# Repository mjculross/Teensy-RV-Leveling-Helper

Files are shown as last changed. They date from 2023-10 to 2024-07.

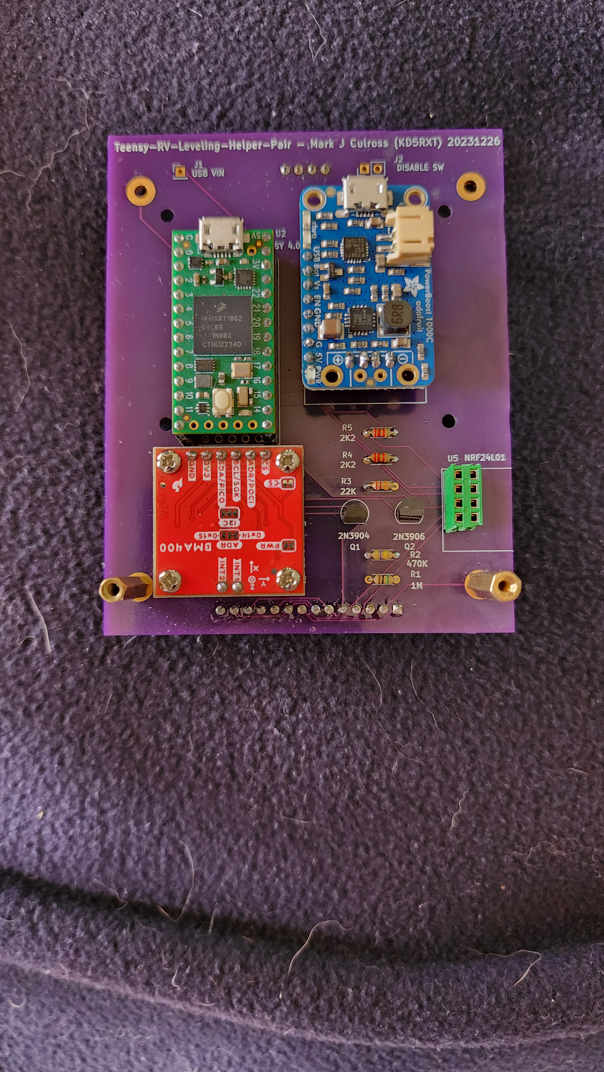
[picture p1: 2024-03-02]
photos/TRLH - pcb component side.jpg

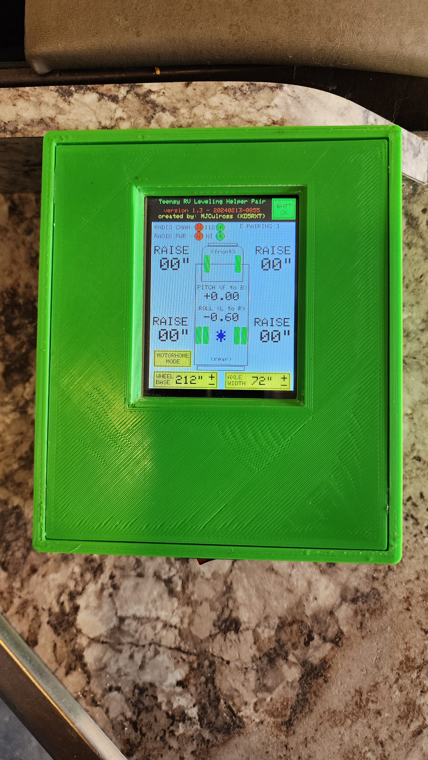
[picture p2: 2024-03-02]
photos/TRLH - display after leveling.jpg

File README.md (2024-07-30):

# Teensy-RV-Leveling-Helper
Teensy RV Leveling Helper using Teensy 4.0 + BMA400 Triple Axis Accelerometer Breakout + ILI9341 Color 320x240 TFT Touchscreen display + NRF24L01 radio

TRLH - RV mode main screen

This project came about after we acquired a used RV motorhome & I quickly grew tired of the following process of attempting to level the RV:
   1) park the RV on a particular site
   2) look at the bubble level on the kitchen counter to determine "level or not"
   3) make/revise my best guess as to how many blocks are required on each wheel to attain "level"
   4) drive the RV up on the best guess number of blocks
   5) if the RV is "level", then you're DONE !!
   6) if the RV is not yet "level", then drive the RV down off of the best guess number of blocks
   7) goto 3) above & repeat several times (until either we're close enough, or I get fed up, whichever comes first)

Using the TRLH makes this process much more convenient & quick as follows:
   1) park your RV where you want it to ultimately rest for the duration of your stay
   2) apply power to the inside TRLH & place it on the kitchen counter inside the RV
      (which provides a non-moving reference plane for the entire RV)
   3) if you are using a second TRLH as a remote display, apply power to the remote TRLH
      (the two units will establish sync over the radio & the remote unit will ignore its
      own accelerometer data, and will instead perform all leveling calculations using
      the accelerometer data received from the inside TRLH over the NRF24L01 radio -
      NOTE: if you're not using the remote TRLH, the inside TRLH will still operate as a
      single unit)
   4) take note of the leveling solution displayed (indicating results of calculating
      how many inches to raise any of the wheels in order to bring the RV to a perfectly
      level position)
   5) back the RV away sufficiently to leave room to put the ramps into place
   6) build and place the required ramps (using 1" blocks) to raise the wheels as indicated
   7) drive the RV up onto the newly built leveling ramps
   8) verify that the TRLH now shows 0" for each wheel - LEVELING SUCCESS !! (Note that
      anything within 1" of level is sufficient for the comfort of the occupants, as
      well as for the equipment, primarily the refrigerator)
   9) sit back & enjoy a cold drink of your choice

This project incorporates the following:

   HARDWARE:

      Teensy 4.0
         available from PJRC.com https://www.pjrc.com/teensy-4-0/

      ILI9341 Color 320x240 TFT Touchscreen display
         available from PJRC.com https://www.pjrc.com/store/display_ili9341_touch.html

      HiLetgo NRF24L01+ Wireless Transceiver Module 2.4GHz
         available from https://www.amazon.com/gp/product/B00LX47OCY
  
      BMA400 Triple Axis Accelerometer Breakout
         available from Sparkfun https://www.sparkfun.com/products/21208

      PowerBoost 1000 Charger - Rechargeable 5V Lipo USB Boost @ 1A - 1000C
         available from Adafruit https://www.adafruit.com/product/2465
         
      Lithium Ion Polymer Battery - 3.7v 2500mAh
         available from Adafruit https://www.adafruit.com/product/328

   This project uses touchscreen input & color display to create a visual (graphical) indication of how many inches of leveling blocks are required to be put under each wheel of an RV to level it
  
   This project uses the ILI9341_t3 library, which has been optimized for use with the Teensy TFT display, as well as the XPT2046_Touchscreen.h touchscreen library for that same display

   This project (optionally) uses the NRF24L01 wireless transceiver module to allow two TRLH units to communicate, using one as the inside unit taking measurements, and the other as a remote display
   
   This project specifically uses the SparkFun BMA400 support library (SparkFun_BMA400_Arduino_Library.h) which can be added using the Arduino IDE library manager.

   This project allows & stores configurable wheel base (front to back wheels distance) from 60" to 255".

   This project allows & stores configurable wheel distance (front wheels, left to right distance) from 60" to 84".

   Internet reference (with equation derivation) for transforming accelerometer x,y,z vector data into pitch & roll angles:

      https://mwrona.com/posts/accel-roll-pitch/

   The specific DPDT switch that I use for power control (& for which the 3D printed case is designed) is the Carling Technologies 62115929-0-0-V, available from digikey as part number 432-1252-ND (https://www.digikey.com/en/products/detail/carling-technologies/62115929-0-0-V/3025077).

   An Adafruit microUSB panel mount extension cable Product ID 3258 (https://www.adafruit.com/product/3258) is mounted on the side wall of the case.  The cable is split such that the USB 5VDC line connects to the USB input pin on the Adafruit PowerBoost 1000C to provide power & battery charging, while the remaining GROUND, D-, & D+ signals connect to the microUSB connector on the Teensy to allow (re)programming without opening the case.

   This project implements the following:

      1) read the XYZ vector from the BMA400 triple axis accelerometer breakout
      2) use the XYZ vector to calculate PITCH and ROLL values for the current plane of the RV/trailer orientation
      3) use the calculated PITCH and ROLL values to determine the highest wheel/point (which will not require any blocks)
      4) use the calculated PITCH and ROLL values to determine the number of inches of blocks required for the remaining wheels/points to achieve "level"
      5) update the display with the current results once per second (& average all values otherwise)
      6) repeat

UPDATE NOTES for version 1.6 dated 07/20/2024 @0635:

   Updated TRAILER MODE such that is now indicates LOWER or RAISE values up to 24" for the
   hitch, and RAISE values up to 12" for the wheels.
   
UPDATE NOTES for version 1.4 dated 04/05/2024 @1335:

   Now, two units can be used & they talk to each other using NRF24L01 wireless modules.
   The first unit powered on will assume that it is the "INSIDE" unit (which is actually
   reading its onboard BMA400 accelerometer & displaying the leveling recommendations from
   the calculated pitch & roll).  The second unit will assume that it is the "OUTSIDE" unit
   (which is ignoring its onboard BMA400, and is instead displaying the leveling
   recommendations calculated using the pitch & roll data received over the NRF24L01
   wireless link from the "INSIDE" unit).  This way, leveling can be achieved without the
   need for running back & forth between inside (to look at the Teensy-RV-Leveling-Helper)
   & outside (to make adjustments).  Any unit can also be used by itself...it does not have
   to have a partner to work.  The latest firmware also automatically detects the lack of
   the NRF24L01 module & operates successfully without the radio as a standalone unit.

   EASTER EGG: If you hold down on the battery status display box for 5-seconds, the unit
   will change from RV LEVELING MODE to LED COLOR CONTROLLER MODE.  In this mode, with a
   WS2812B LED strip powered from the 5VDC supply & common ground with the Teensy, tie the
   data line to PIN 8 & the RV Leveling Helper can also be used to create custom LED
   patterns, with the ability to control the mode (MARQUIS, CYCLE, FADE, CROSSFADE, ZIPPER,
   & RANDOM), the brightness, the radio power level (for using another unit as a remote
   control), the radio channel (to put the LED COLOR CONTROLLER MODE on a different radio
   channel from the RV LEVELING MODE to minimize interference between them).  Up to ten
   different custom patterns can be stored in EEPROM for quick recall.  Each pattern can
   be from two to thirty-two LEDs in length.  Each LED can be set to any of over sixteen
   million colors.  You can also customize the speed for each pattern individually, as
   well as the direction of movement (FORWARD / REVERSE).  An RV Leveling Helper which
   is being operated in LED COLOR CONTROLLER MODE need not have the TFT Color Touchscreen
   installed/connected.  By shorting PIN 10 on the Teensy to ground, an RV Leveling
   Helper unit can be forced into LED COLOR CONTROLLER MODE (specifically for the case
   where you have an RV Leveling helper unit that does not have a display connected by
   which to change between the two modes, essentially making it a dedicated, stand-alone
   LED COLOR CONTROLLER).  For the RV Leveling Helper with a TFT Color Touchscreen
   installed/connected and operting in the LED COLOR CONTROLLER MODE, holding down on
   the battery display box for 5-seconds will change it back to RV LEVELING MODE.  So,
   you now have two-controllers-in-one with this new capability.
   
RV LEVELING CONTROLLER OPERATIONAL MODE:

   This project can be switched between the following primary modes of operation:
   - RV mode (four points of balance/leveling = four wheels)
   - Trailer mode (three points of balance/leveling = two wheels and the hitch)
   - Bubble mode (traditional 2-D bubble level)

MECHANICAL ASSEMBLY & CALIBRATION:

   For information on mechanical assembly and/or calibration, see the "readme" file in the "photos" folder.

ORDERING INFO:

   The compact PCB is available from OshPark here: https://oshpark.com/projects/CN9rpz97/order

CONTACT INFO:

If you have any questions, suggestions for improvement, and most especially any bug reports, please contact me at kd5rxt@arrl.net

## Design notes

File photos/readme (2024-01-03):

MECHANICAL ASSEMBLY:

For the case mechanical assembly, reference the "TeensyRVLevelingCalculator - mechanical view.pdf file to identify the unique parts by color, and perform the following:
Four M2.5 x 10mm screws (RED) are inserted from the bottom, passing thru the case bottom.  Using four M2.5 nuts (SILVER), one is installed onto each screw and hand-tightened around the case bottom.  These nuts are secured to the screw using blue threadlocker, a conservative amount of which is applied to the top of each nut such that the threadlocker liquid penetrates between the screw threads and the nuts.  Four M2.5x11+6 threaded stand-offs (MAGENTA) are secured with four M2.5 nuts (NOT SHOWN) to the prototype board (GREEN) which holds all of the electronic parts.  These stand-offs secured to the prototype board are carefully aligned with the four screws inserted thru the case bottom.  The screws are tightened only halfway into the stand-offs, leaving the ability to adjust each screw individually in order to calibrate the absolute level of the project (see the CALIBRATION section below).  Four 20mm x 5mm rubber feet (with a hole punched into the center of each) are placed on the bottom, allowing access to the adjustment screws thru the center punched holes.

CALIBRATION:

Preparation:
- set the wheel base and the axle width both to 60"

Step #1:
- place the project on a surface that is only slightly unlevel (less than 3 degrees off in any direction) with the primary slope oriented between front & back
- pay particular attention to the location placement of the project case
- note the initial PITCH angle reported (pitch_i)
- rotate the project case 180 degrees, making sure the place the project case back as close to the same spot as before
- note the rotated PITCH angle reported (pitch_r)
- rotate the project case 180 degrees, making sure the place the project case back as close to the same spot as before
- adjust the two screws at the top and/or bottom of the project case equally (raising and/or lowering the top and/or bottom of the project case as required) and repeat Step #1 as many times as necessary until pitch_i is approximately equal to the negative of pitch_r, centered around 0 degrees

Step #2:
- place the project on a surface that is only slightly unlevel (less than 3 degrees off in any direction) with the primary slope oriented between left & right
- pay particular attention to the location placement of the project case
- note the initial ROLL angle reported (roll_i)
- rotate the project case 180 degrees, making sure the place the project case back as close to the same spot as before
- note the rotated ROLL angle reported (roll_r)
- rotate the project case 180 degrees, making sure the place the project case back as close to the same spot as before
- adjust the two screws at the left and/or right side of the project case equally (raising and/or lowering the left and/or right side of the project case as required) and repeat Step #2 as many times as necessary until roll_i is approximately equal to the negative of roll_r, centered around 0 degrees

Step #3"
- repeat Step #1 above to cross-check the front-to-back calibration

Final Steps:
- reset the wheel base and the axle width as appropriate for your RV/trailer
- from the bottom of the case (thru the center punched rubber feet), apply hot glue to the tops of the adjustment screws (filling the center punched holes in the rubber feet to just shy of level with the top of the rubber feet - the tops of the rubber feet should rest on whatever surface the project is set upon, without any interference from the hot glue) in order to secure the screws in place, thus preserving the calibration just performed

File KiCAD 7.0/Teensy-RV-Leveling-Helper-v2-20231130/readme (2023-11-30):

This set of KiCAD design files is for the updated v2 (compact 3.0" x 3.8") PCB for the 20231130 version of the Teensy-RV-Leveling-Helper.

The included schematic includes external connection points as follows (with connectivity description in parentheses):
- USB VIN (input 5VDC from the external USB connector)
- DISABLE IN (use an external switch to connect the EN input on the Adafruit PowerBoost 1000C to GROUND to deactivate the project)

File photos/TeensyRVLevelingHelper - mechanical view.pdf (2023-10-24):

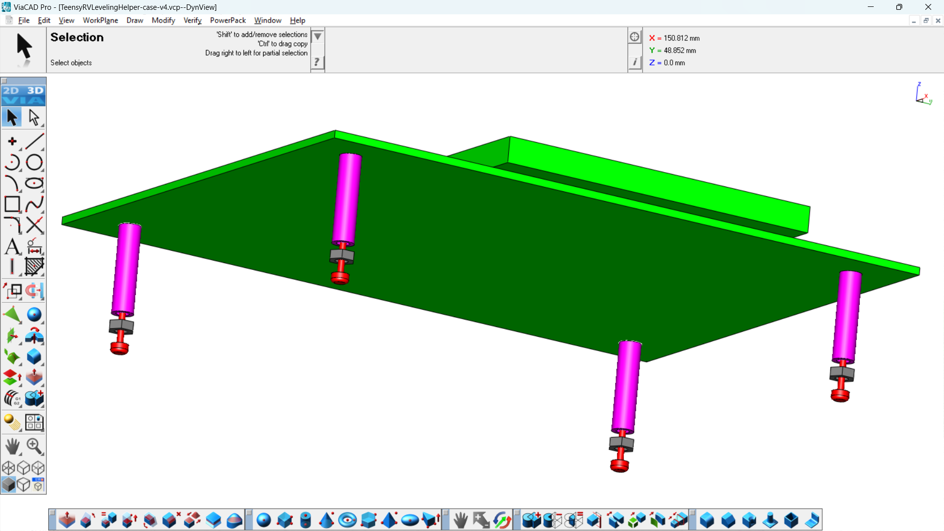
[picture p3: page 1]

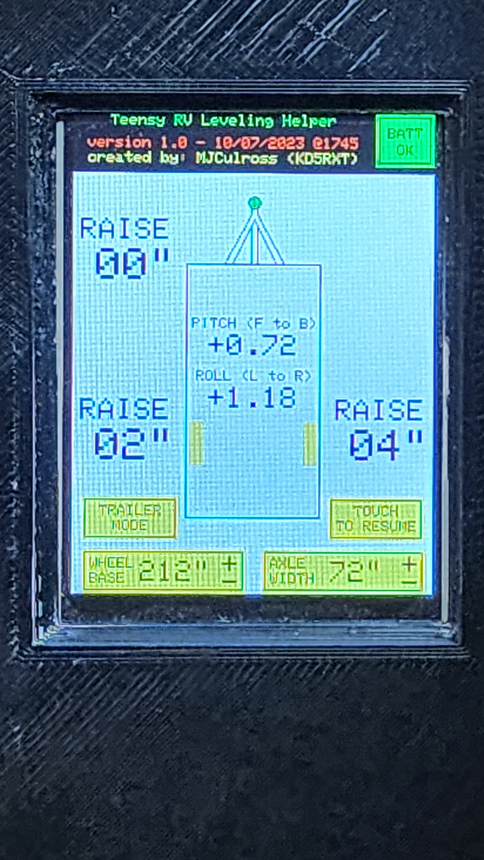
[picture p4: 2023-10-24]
photos/TRLH - Trailer mode main screen.jpg

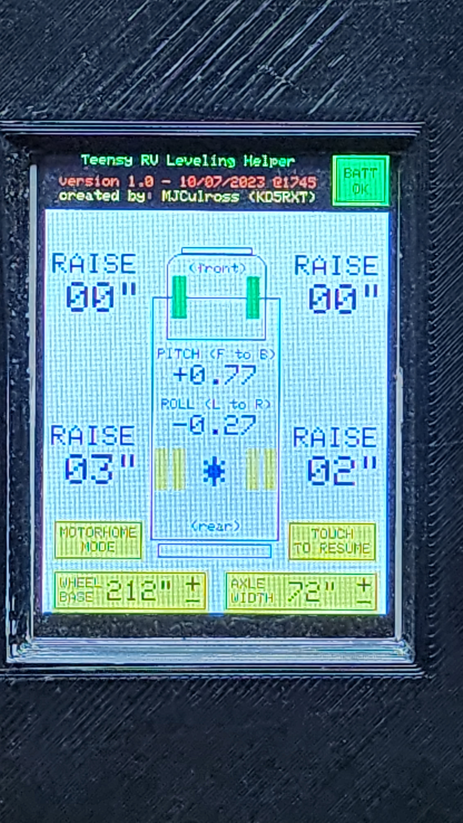
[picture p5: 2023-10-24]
photos/TRLH - RV mode main screen.jpg

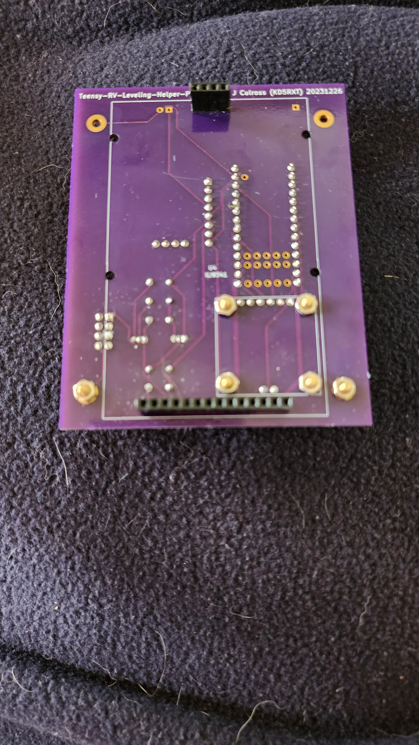
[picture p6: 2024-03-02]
photos/TRLH - pcb display and battery side.jpg

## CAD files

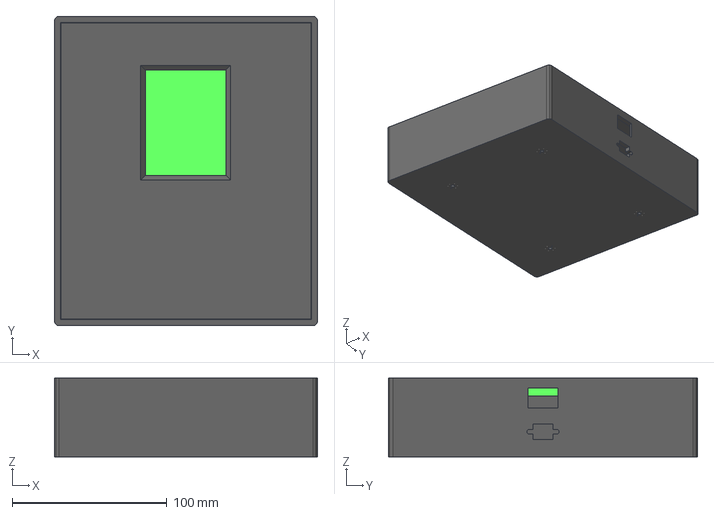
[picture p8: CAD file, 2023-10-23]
3D CAD files/TeensyRVLevelingHelper-case-v4.stp
170.0 x 200.0 x 51.0 mm

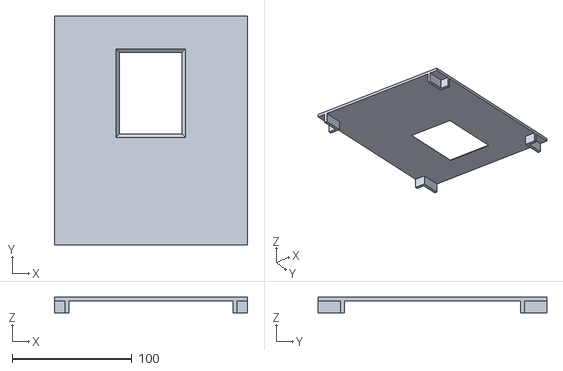
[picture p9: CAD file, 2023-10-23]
3D CAD files/TeensyRVLevelingHelper-case-v4-lid.stl
161.5 x 191.5 x 13.0

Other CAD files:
3D CAD files/TeensyRVLevelingHelper-case-v4.dwg
3D CAD files/TeensyRVLevelingHelper-case-v4.dxf

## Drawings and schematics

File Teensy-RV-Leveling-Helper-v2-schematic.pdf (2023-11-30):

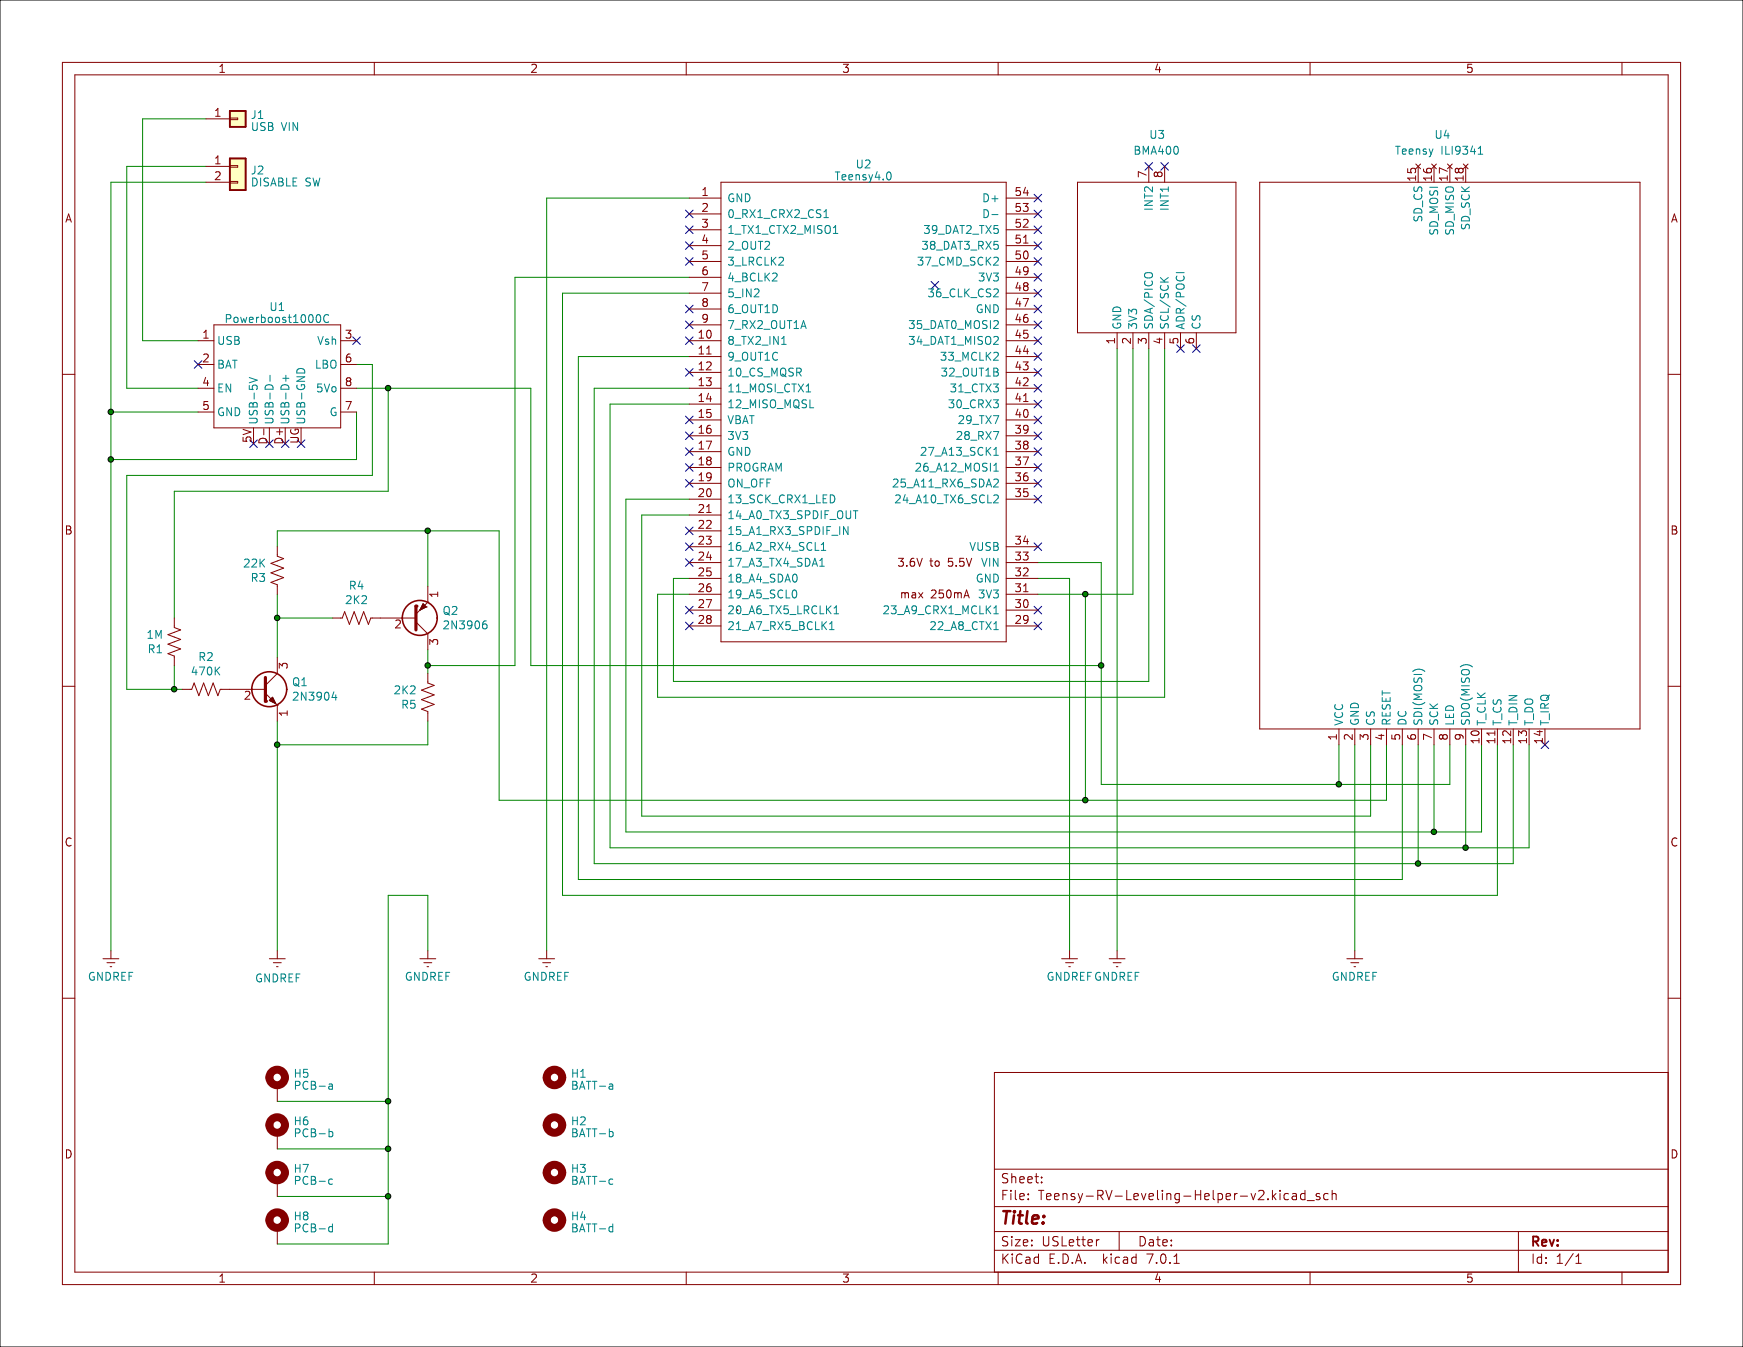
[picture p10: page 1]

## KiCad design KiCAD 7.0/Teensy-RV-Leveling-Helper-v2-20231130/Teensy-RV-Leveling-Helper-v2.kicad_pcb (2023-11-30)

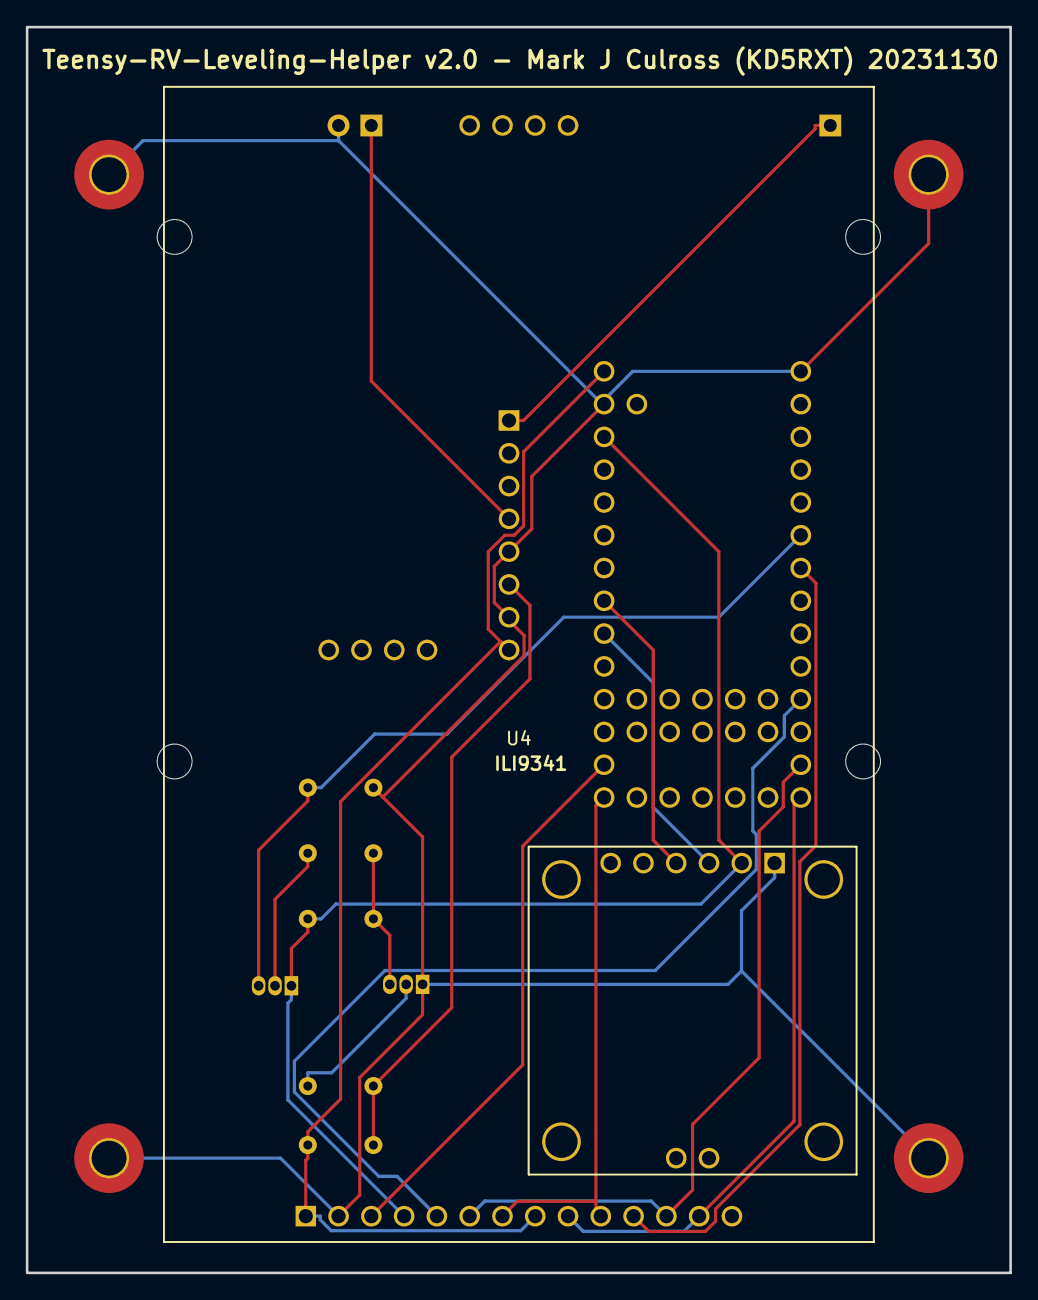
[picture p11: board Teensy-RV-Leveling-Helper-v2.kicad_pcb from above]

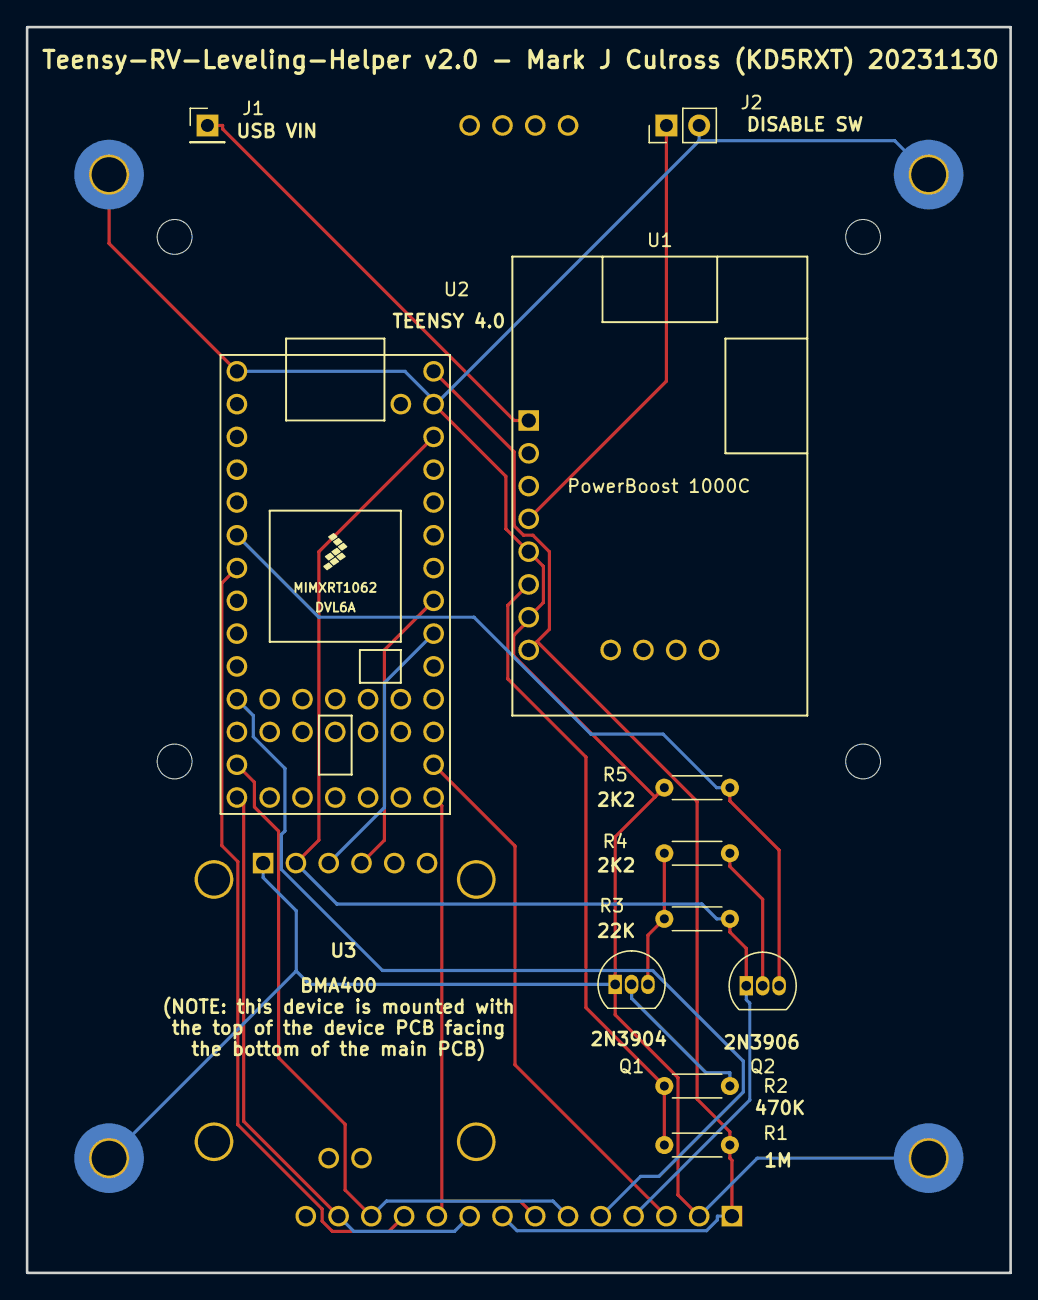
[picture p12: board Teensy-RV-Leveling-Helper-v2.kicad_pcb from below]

Board: 2 copper layers, 76.2 x 96.5 mm, 21 parts (11 on the bottom side), 18 nets.

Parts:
H1: BATT-a; MountingHole_2.7mm
H2: BATT-b; MountingHole_2.7mm
H3: BATT-c; MountingHole_2.7mm
H4: BATT-d; MountingHole_2.7mm
H5: PCB-a; MountingHole_2.7mm_M2.5_Pad_TopBottom
H6: PCB-b; MountingHole_2.7mm_M2.5_Pad_TopBottom
H7: PCB-c; MountingHole_2.7mm_M2.5_Pad_TopBottom
H8: PCB-d; MountingHole_2.7mm_M2.5_Pad_TopBottom
J1: USB VIN; PinHeader_1x01_P2.54mm_Vertical
J2: DISABLE SW; PinHeader_1x02_P2.54mm_Vertical
Q1: 2N3904; TO-92_Inline
Q2: 2N3906; TO-92_Inline
R1: 1M; R_Axial_DIN0204_L3.6mm_D1.6mm_P5.08mm_Horizontal
R2: 470K; R_Axial_DIN0204_L3.6mm_D1.6mm_P5.08mm_Horizontal
R3: 22K; R_Axial_DIN0204_L3.6mm_D1.6mm_P5.08mm_Horizontal
R4, R5: 2K2; R_Axial_DIN0204_L3.6mm_D1.6mm_P5.08mm_Horizontal
U1: Powerboost1000C; PowerBoost1000C
U2: Teensy4.0; Teensy40
U3: BMA400
U4: Teensy ILI9341; ILI9341

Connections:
GNDREF: H5.1, H6.1, H7.1, H8.1, J2.2, Q1.1 (E), R5.1, U1.5 (GND), U1.7 (G), U2.1 (GND), U2.32 (GND), U3.1 (GND), U4.2 (GND)
unnamed: J1.1, U1.1 (USB)
unnamed: J2.1, U1.4 (EN)
unnamed: Q1.2 (B), R2.2
unnamed: Q1.3 (C), R3.1, R4.1
unnamed: Q2.2 (B), R4.2
unnamed: Q2.3 (C), R5.2, U2.6 (4_BCLK2)
unnamed: Q2.1 (E), R3.2, U2.31 (3V3), U3.2 (3V3), U4.4 (RESET)
unnamed: R1.2, U1.8 (5Vo), U2.33 (VIN), U4.1 (VCC), U4.8 (LED)
unnamed: R1.1, R2.1, U1.6 (LBO)
unnamed: U2.7 (5_IN2), U4.11 (T_CS)
unnamed: U2.11 (9_OUT1C), U4.5 (DC)
unnamed: U2.13 (11_MOSI_CTX1), U4.6 (SDI(MOSI)), U4.12 (T_DIN)
unnamed: U2.14 (12_MISO_MQSL), U4.9 (SDO(MISO)), U4.13 (T_DO)
unnamed: U2.20 (13_SCK_CRX1_LED), U4.7 (SCK), U4.10 (T_CLK)
unnamed: U2.21 (14_A0_TX3_SPDIF_OUT), U4.3 (CS)
unnamed: U2.25 (18_A4_SDA0), U3.3 (SDA/PICO)
unnamed: U2.26 (19_A5_SCL0), U3.4 (SCL/SCK)

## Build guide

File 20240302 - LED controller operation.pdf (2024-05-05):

LED Controller Operations
(last updated 20240302)

Page 1 of 3

NOTES:

- Make sure to turn the LED controller board (& attached LED string) on first, then turn the remote controller board on.
- To turn the LED controller board on, connect the power supply to the LED string.
- To turn the remote controller board on, remove the jumper on the “DISABLE SW” & place it onto just one of the pins (for storage, so it isn't lost).
- To turn the LED controller board off, disconnect the power supply (or just unplug the power supply from the wall).
- To turn the remote controller board off, replace the jumper on the “DISABLE SW” onto both pins.
- With power applied to both boards, the remote controller board should display “REMOTE CONTROL”, which indicates that the two boards are successfully communicating.
- With power applied to both boards, if the remote controller board display shows “PAIRING”, then the two boards are not communicating (check the channel number and the power level on the remote controller board – see below)
- The boards can store 10 unique patterns for quick recall.
- Each pattern can be from 1 to 32 LEDs in length (& the configured pattern will be repeated to fill the entire LED string).
- Each pattern storage includes the following: pattern number, pattern type, pattern speed, and pattern length.
- Brightness is universal (applied to any/all patterns).

CONTROLS:

LEDS ON/OFF: | This control can be used to toggle the entire LED string ON/OFF.
SET/READ LED: | Touch this button to toggle between “SET LED” mode and “READ LED” mode. When this control indicates “SET LED”, then the currently configured color will be stored in any LEDs that are touched as part of the currently selected pattern. When this control indicates “READ LED”, then the current configured color will change to the color of any LED that is subsequently touched, and the control will return to “SET LED” mode.
LOAD PATTERN: | This control causes the currently selected pattern number to be loaded from storage (NOTE: the pattern is not sent to the LED string until either the SAVE PATTERN button is pressed, or the APPLY PATTERN button is pressed).
SAVE PATTERN: | This control allows the currently defined/displayed pattern of LED colors to be stored in the selected pattern number (& the pattern is also sent to the LED string).
APPLY PATTERN: | This control causes the currently selected pattern to be sent to the LED string.
RADIO POWER: | Generally, leave this set to HIGH (maximum control range, approximately 50 feet).
RADIO CHANNEL: | Generally, leave this on channel 113 (default).
BRIGHT LEVEL: | Brightness can be configured at levels 1-8, where 8 is the brightest.
PATTERN NUMBER: | The number of the currently active pattern.
PATTERN TYPE: | The pattern types include the following (see below for details): MARQUIS-FWD, MARQUIS-REV, CYCLE-FWD, CYCLE-REV, FADE-FWD, FADE-REV, XFADE-FWD, XFADE-REV, ZIPPER-FWD, ZIPPER-REV, and RANDOM.

Page 2 of 3

PATTERN SPEED: | Pattern speed can be configured at levels 0-20, where 0 causes no cycling of the active pattern (the pattern in stationary), and 20 causes the quickest cycling of the pattern.
PATTERN LENGTH: | Pattern length can be set between 1 & 32 LEDs in the pattern (unused LEDs will be displayed as gray).
COLORS: | The currently configured color (to be set into any of the LEDs in the current pattern) can be adjusted using the “+/-” controls on each of the RED, GREEN, and BLUE primary color adjustment controls. Clicking on the “+” will increase the intensity of that particular primary color, and clicking on the “-” will decrease the intensity of that particular primary color. Clicking on the number will quickly adjust the intensity of that particular primary color, cycling thru values of 0 (fully off), 63 (1/4 on), 127 (1/2 on), 191 (3/4 on), and 255 (fully on). The resulting mix of the selected intensities of the primary colors is shown in the rectangle to the right of the primary color adjustments. When the “READ LED” capability is used (see above), then the settings of the primary color adjustments will be (re)set to match the current color of the LED clicked.

PATTERNS:

MARQUIS-FWD: | The LEDs in the active length of the pattern are displayed sequentially, starting with the first LED defined in the pattern, forward thru the last LED defined in the pattern, with the pattern repeated to fill the entire LED string. This pattern of LEDs will be moved in the “forward” direction (moving away from the LED controller board) at the rate determined by the pattern speed setting.
MARQUIS-REV: | The LEDs in the active length of the pattern are displayed sequentially, starting with the last LED defined in the pattern, in reverse thru the first LED defined in the pattern, with this reverse pattern repeated to fill the entire LED string. This pattern of LEDs will be moved in the “reverse” direction (moving towards the LED controller board) at the rate determined by the pattern speed setting.
CYCLE-FWD: | The entire LED string will be lit with the LED colors defined in the pattern, starting with the color of the first LED in the pattern, forward thru the color of the last LED in the pattern, then back to the color of the first LED in the pattern to repeat the colors in forward order. This forward cycling of LEDs will occur at the rate determined by the pattern speed setting.
CYCLE-REV: | The entire LED string will be lit with the LED colors defined in the pattern, starting with the color of the last LED in the pattern, in reverse thru the color of the first LED in the pattern, then back to the color of the last LED in the pattern to repeat the colors in reverse order. This reverse cycling of LEDs will occur at the rate determined by the pattern speed setting.
FADE-FWD: | The entire LED string will be lit with the LED colors defined in the pattern, starting with the color of the first LED in the pattern, which will fade into view with increasing brightness (up to the brightness level currently selected), then will fade out of view with decreasing brightness (down until the LEDs are off), forward thru the color of the last LED in the pattern (each color fading in, then out), then back to the color of the first LED in the pattern to repeat the colors in forward order. This fading in and out of LEDs in forward order will occur at the rate determined by the pattern speed setting.
FADE-REV: | The entire LED string will be lit with the LED colors defined in the pattern, starting with the color of the last

Page 3 of 3

LED in the pattern, which will fade into view with increasing brightness (up to the brightness level currently selected), then will fade out of view with decreasing brightness (down until the LEDs are off), in reverse thru the color of the first LED in the pattern (each color fading in, then out), then back to the color of the last LED in the pattern to repeat the colors in reverse order. This fading in and out of LEDs in reverse order will occur at the rate determined by the pattern speed setting.

XFADE-FWD: | The entire LED string will be lit with a mixture of two adjacent LED colors defined in the pattern, starting with the color of the first LED in the pattern at the currently selected brightness level, and the color of the next LED at zero brightness. The brightness of the first LED color will fade down, while at the same time, the brightness of the next LED color will fade up, resulting in a transitioning mixture of the colors of the two adjacent LEDS. Once the first LED color is completely faded out, the choice of the two LEDs for the mix will advance in adjacent pairs thru the LEDs defined in the pattern, repeating the choice of adjacent LED colors in forward order. This cross-fading of LEDs in forward order will occur at the rate determined by the pattern speed setting.
XFADE-REV: | The entire LED string will be lit with a mixture of two adjacent LED colors defined in the pattern, starting with the color of the last LED in the pattern at the currently selected brightness level, and the color of the previous LED at zero brightness. The brightness of the last LED color will fade down, while at the same time, the brightness of the previous LED color will fade up, resulting in a transitioning mixture of the colors of the two adjacent LEDS. Once the last LED color is completely faded out, the choice of the two LEDs for the mix will advance in adjacent pairs thru the LEDs defined in the pattern, repeating the choice of adjacent LED colors in reverse order. This cross-fading of LEDs in reverse order will occur at the rate determined by the pattern speed setting.
ZIPPER-FWD: | The entire LED string will be lit from the end closest to the controller to the end farthest from the controller, one LED at a time until the entire LED string is lit in the color of the first LED in the current pattern. The entire LED string will then be lit from the end closest to the controller to the end farthest from the controller, one LED at a time until the entire LED string is lit in the color of the second LED in the current pattern. This progression will repeat thru the colors of the LEDs in the current pattern in forward order. Once the color of the last LED in the current pattern has been used to fill the entire LED string, the pattern repeats in the forward direction, starting with the color of the first LED in the current pattern. This zipper replacement of LEDs in forward order will occur at the rate determined by the pattern speed setting.
ZIPPER-REV: | The entire LED string will be lit from the end farthest from the controller to the end closest to the controller, one LED at a time until the entire LED string is lit in the color of the last LED in the current pattern. The entire LED string will then be lit from the end farthest from the controller to the end closest to the controller, one LED at a time until the entire LED string is lit in the color of the next to the last LED in the current pattern. This progression will repeat thru the colors of the LEDs in the current pattern in reverse order. Once the color of the first LED in the current pattern has been used to fill the entire LED string, the pattern repeats in the reverse direction, starting with the color of the last LED in the current pattern. This zipper replacement of LEDs in reverse order will occur at the rate determined by the pattern speed setting.
RANDOM: | Each the colors of the LEDs in the current pattern are randomly placed along the length of the LED string, and this random placement of LED colors is randomly changed at a rate determined by the current pattern speed.

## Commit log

2023-10-23 Create Teensy-RV-Leveling-helper.ino
    Version of Teensy-RV-Leveling-Helper.ino 1.0 dated 10/07/2023 @1745
2023-10-23 Add files via upload
    KiCAD 7.0 project with a simple schematic of the Teensy-RV-Leveling-Helper project.
    [Teensy-RV-Leveling-Helper-v1.kicad_pcb, Teensy-RV-Leveling-Helper-v1.kicad_sch]
2023-10-23 Create readme
    added description of the connections to the external DPDT Power Switch
2023-11-29 Add files via upload
    Updated to include new PCB
    [Teensy-RV-Leveling-Helper-v1.kicad_pcb, Teensy-RV-Leveling-Helper-v1.kicad_sch]
2023-11-30 Create separate repositories for v1 & v2 PCBs
2023-12-24 added PCB ordering info
2023-12-24 corrected PCB ordering info
2023-12-24 updated PCB ordering info
2023-12-28 Updated firmware - now supports optional NRF24L01
    Now, two units can be used & they talk to each other using NRF24L01 wireless modules. The first unit powered on will assume that it is the "INSIDE" unit (which is actually reading its onboard BMA400 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
2024-01-03 Updated to allow automatic button repeats
2024-01-03 Updated the calibration procedure for clarity
2024-05-05 Update README to include information on the new LED COLOR CONTROLLER MODE
2024-05-05 Instructions for using LED COLOR CONTROLLER MODE
2024-05-05 Update to include info on LED COLOR CONTROLLER MODE
